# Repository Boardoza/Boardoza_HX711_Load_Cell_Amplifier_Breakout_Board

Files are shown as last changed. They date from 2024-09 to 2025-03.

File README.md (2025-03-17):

# Boardoza HX711 24-Bit ADC Module

The HX711 24-Bit Analog-to-Digital Converter (ADC) Module is designed for precision load cell measurements, making it ideal for electronic weighing scales and industrial control applications. It features a low-noise programmable gain amplifier and supports two selectable differential input channels. The module operates with low power consumption, making it suitable for battery-powered applications.

## [Click here to purchase!](https://ozdisan.com/maker-ve-iot-urunleri/boardoza/boardoza-modulleri/BOARDOZA-HX711/1206514)

|Front Side|Back Side|
|:---:|:---:|
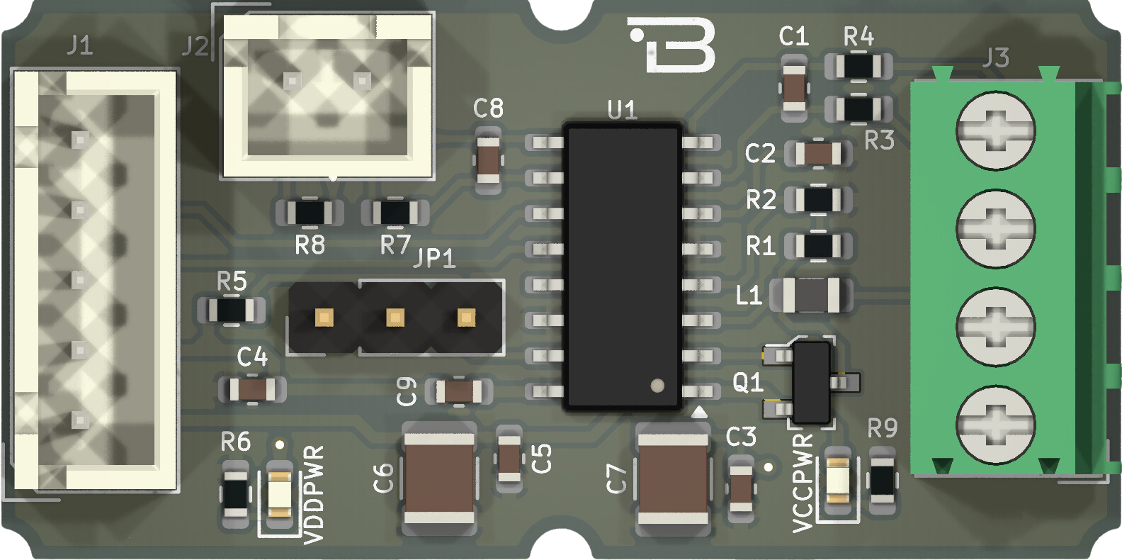
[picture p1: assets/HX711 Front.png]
HX711 Front
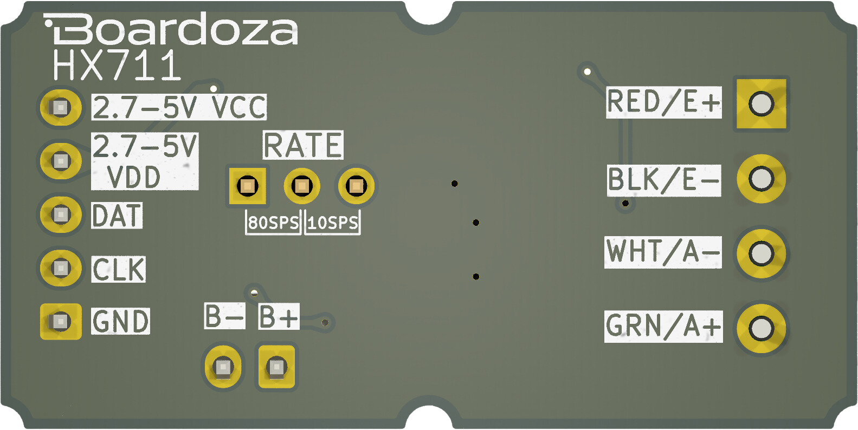
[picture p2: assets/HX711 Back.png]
HX711 Back
| | |

---

## Key Features

- 24-bit ADC designed for weigh scales and industrial applications.
- Two selectable differential input channels (To use channel B, R7(100R), R8(100R), and C8(100nF) must be populated).
- Low power consumption: <1.5mA in normal operation, <1µA in power-down mode.
- Integrated low-noise programmable gain amplifier.
- Selectable output data rates: 10SPS or 80SPS.
- Wide operating voltage range: 2.7V to 5.5V.

---

## Technical Specifications

**Input Voltage:** 2.7V - 5.5V  
**Functions:** 24-Bit ADC for load cells and weigh scales  
**Supply Current:** 1.5mA  
**Operating Temperature:** -40°C ~ +85°C  
**Board Dimensions:** 20mm x 40mm  

---

## Board Pinout

### J1 Connector

| Pin Number | Pin Name | Description |
| :---: | :---: | --- |
| 1 | VCC | 2.7V - 5.5V Power Input |
| 2 | VDD | 2.7V - 5.5V Power Input |
| 3 | DAT | Serial Data Output |
| 4 | CLK | Serial Clock Input |
| 5 | GND | Ground |

### J2 Connector

| Pin Number | Pin Name | Description |
| :---: | :---: | --- |
| 1 | B+ | Positive Signal (Second Channel) |
| 2 | B- | Negative Signal (Second Channel) |

### J3 Connector (Load Cell Interface)

| Pin Number | Pin Name | Description |
| :---: | :---: | --- |
| 1 | RED/E+ | + Excitation |
| 2 | BLK/E- | - Excitation |
| 3 | WHT/A- | - Signal |
| 4 | GRN/A+ | + Signal |

### JP1 Jumper Settings

| Pin Configuration | Data Rate |
| :---: | --- |
| 1-2 | 80 Samples per Second (SPS) |
| 2-3 | 10 Samples per Second (SPS) |

---

## Board Dimensions

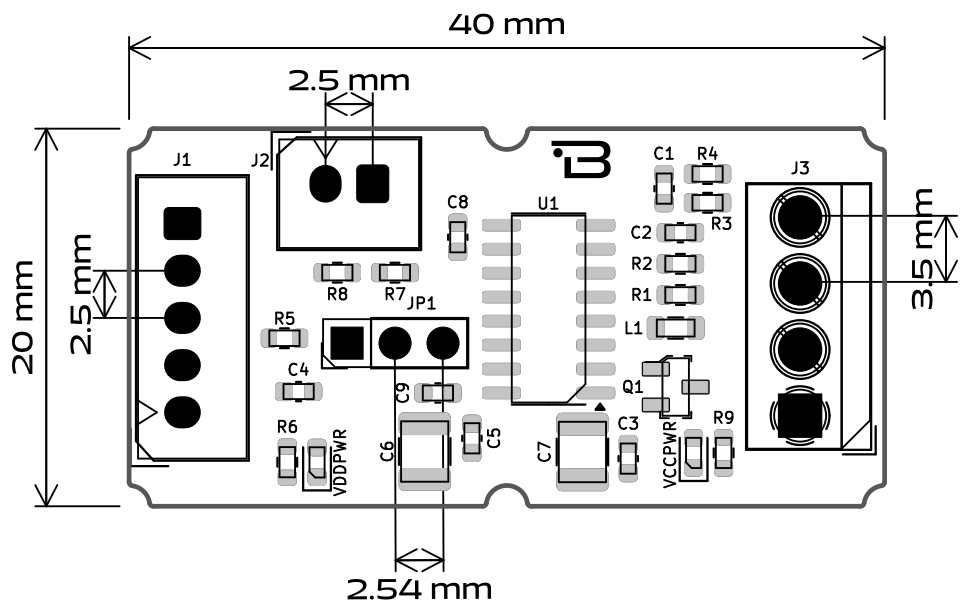
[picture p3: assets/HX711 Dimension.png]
HX711 Dimension


---

## Step Files

[Boardoza HX711.step](./assets/HX711%20Step.step)

---

## Datasheet

[Boardoza HX711 Datasheet.pdf](./assets/HX711%20Datasheet.pdf)

---

## Version History

- V1.0.0 - Initial Release

---

## Support

- If you have any questions or need support, please contact <support@boardoza.com>

---

## License

Shield: [][cc-by-sa]

This work is licensed under a [Creative Commons Attribution-ShareAlike 4.0 International License][cc-by-sa].

[][cc-by-sa]

[cc-by-sa]: http://creativecommons.org/licenses/by-sa/4.0/
[cc-by-sa-image]: https://licensebuttons.net/l/by-sa/4.0/88x31.png
[cc-by-sa-shield]: https://img.shields.io/badge/License-CC%20BY--SA%204.0-lightgrey.svg

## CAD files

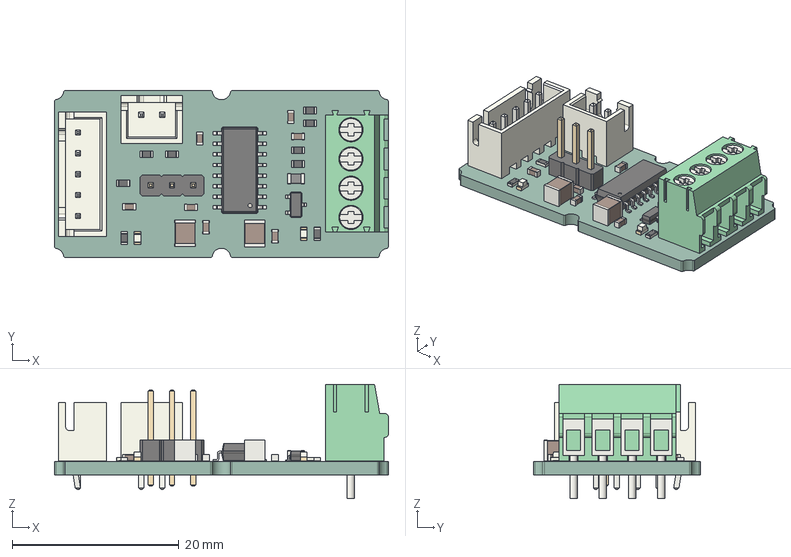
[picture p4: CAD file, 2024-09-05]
assets/HX711 Step.step
40.0 x 20.0 x 13.7 mm
R_0603_1608Metric x 9
LED_0603_1608Metric x 2
C_0603_1608Metric x 7
L_0805_2012Metric
TerminalBlock_Phoenix_PT_15_4_35_H_1x04_P350mm_Horizontal
C_1210_3225Metric x 2
JST_B5B_XH_A
SOP_16_44x104mm_P127mm
PinHeader_1x03_P254mm_Vertical
SOT_23
JST_B2B_XH_A
_autosave-B-HX711-BRK-01MBR-R01_PCB

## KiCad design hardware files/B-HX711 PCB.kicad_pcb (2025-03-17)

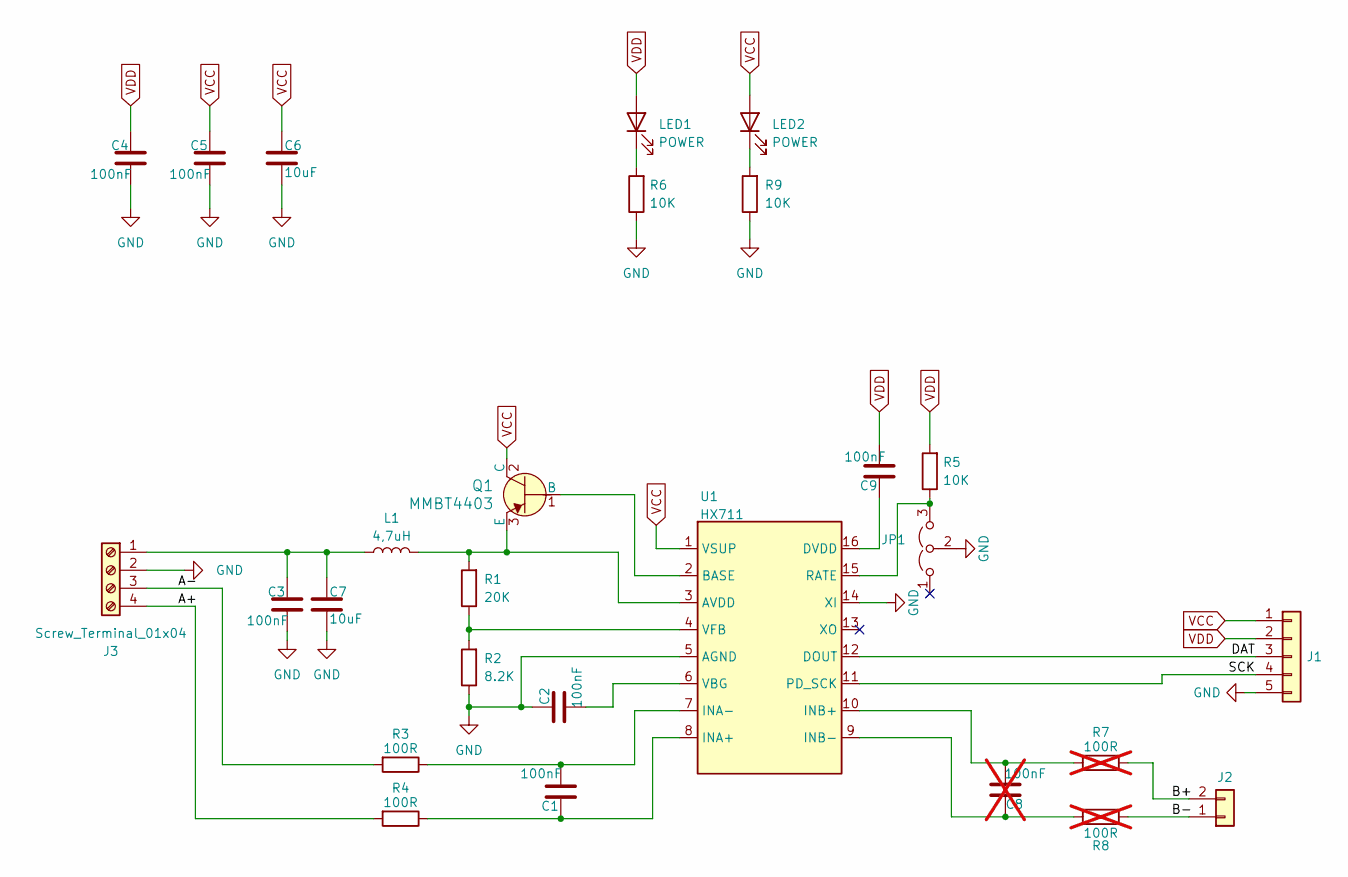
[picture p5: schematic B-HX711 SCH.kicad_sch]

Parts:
C1, C2, C3, C4, C5, C9: 100nF; C_0603_1608Metric; MPN CL10B104KB8NNNC
C6, C7: 10uF; C_1210_3225Metric; MPN CL10A106KQ8NNNC
C8: 100nF; C_0603_1608Metric; not fitted
J1: Conn_01x05; 2317-05S_1x05_P2.50mm_Vertical
J2: Conn_01x02; 2317-02S_1x02_P2.50mm_Vertical; MPN DG350-3.5-02P-14-00AH
J3: Screw_Terminal_01x04; TerminalBlock_MetzConnect_Type059_RT06304HBWC_1x04_P3.50mm_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; MPN DG350-3.5-02P-14-00AH
JP1: Jumper_3_Open; PinHeader_1x03_P2.54mm_Vertical; MPN L-KLS1-207-1-03-S
L1: 4,7uH; L_0805_2012Metric
LED1, LED2: POWER; LED_0603_1608Metric; MPN 19-213USRC/S259/TR8
Q1: MMBT4403; SOT-23-3; MPN MMBT4403_R1_00001
R1: 20K; R_0603_1608Metric; MPN 0603SAJ0203T5E
R2: 8.2K; R_0603_1608Metric; MPN 0603SAJ0822T5E
R3, R4: 100R; R_0603_1608Metric; MPN CQ03SAJ0101T5E
R5, R6, R9: 10K; R_0603_1608Metric; MPN 0603SAJ0103T5E
R7, R8: 100R; R_0603_1608Metric; not fitted
U1: HX711; SOP-16_3.9x9.9mm_P1.27mm; MPN HX711

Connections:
/A+: J3.4, R4.2
/A-: J3.3, R3.2
/B+: J2.2, R7.1
/B-: J2.1, R8.1
/DAT: J1.3, U1.12 (DOUT)
/SCK: J1.4, U1.11 (PD_SCK)
GND: C2.1, C3.1, C4.1, C5.1, C6.2, C7.2, J1.5, J3.2, JP1.2 (C), R2.1, R6.1, R9.1, U1.5 (AGND), U1.14 (XI)
unnamed: C3.2, C7.1, J3.1, L1.1
unnamed: JP1.3 (B), R5.1, U1.15 (RATE)
unnamed: LED1.1 (K), R6.2
unnamed: LED2.1 (K), R9.2
unnamed: Q1.1 (B), U1.2 (BASE)
unnamed: L1.2, Q1.3 (E), R1.2, U1.3 (AVDD)
unnamed: C9.1, U1.16 (DVDD)
unnamed: C1.1, R4.1, U1.8 (INA+)
unnamed: C1.2, R3.1, U1.7 (INA-)
unnamed: C8.2, R7.2, U1.10 (INB+)
unnamed: C8.1, R8.2, U1.9 (INB-)
unnamed: C2.2, U1.6 (VBG)
unnamed: R1.1, R2.2, U1.4 (VFB)
VCC: C5.2, C6.1, J1.1, LED2.2 (A), Q1.2 (C), U1.1 (VSUP)
VDD: C4.2, C9.2, J1.2, LED1.2 (A), R5.2

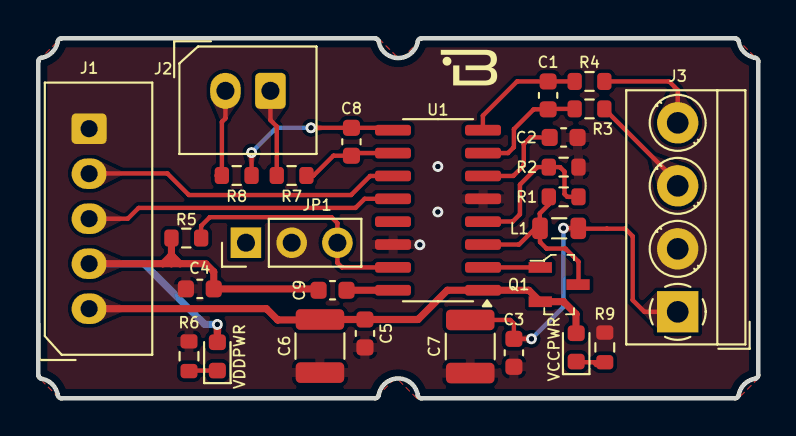
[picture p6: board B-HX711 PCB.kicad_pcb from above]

Board: 2 copper layers, 40.0 x 20.0 mm, 27 parts (0 on the bottom side), 22 nets.

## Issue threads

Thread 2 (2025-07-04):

SCHEMATIC?

lavara123, 2025-07-04:
SCHEMATIC mevcut mu veya vcc vdd ayrımı tam var mı yani

3v3 seviyesinde mcu:
3v3 = vdd
5v = vcc
GND = ortak

Tarzında kullanılabilir mi mcu ya zarar verir mi?

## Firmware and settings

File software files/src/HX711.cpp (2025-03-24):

#include "HX711.h"

int32_t offSetValue = 0;
/**
 * @brief Constructor for the HX711 class.
 * 
 * @param data Data pin connected to the HX711 module.
 * @param clock Clock pin connected to the HX711 module.
 */
HX711::HX711(byte data, byte clock) {
    dataPin = data;
    clockPin = clock;
}

/**
 * @brief Initializes the HX711 module.
 * 
 * This function initializes the HX711 module by beginning communication with Wire, setting data pin as INPUT, clock pin as OUTPUT,
 * powering down the module, delaying for 10 microseconds, and then powering up the module.
 */
void HX711::begin() {
    Wire.begin();
    pinMode(dataPin, INPUT);
    pinMode(clockPin, OUTPUT);
    powerDown();
    delayMicroseconds(10);
    powerUp();
}

/**
 * @brief Checks if the HX711 module is ready for data retrieval.
 * 
 * This function checks if the HX711 module is ready for data retrieval by reading the data pin and checking if it is LOW.
 * @return True if the module is ready, false otherwise.
 */
bool HX711::isReady() {
    return digitalRead(dataPin) == LOW;
}

/**
 * @brief Retrieves the raw value from the HX711 module.
 * 
 * This function retrieves the raw value from the HX711 module based on the specified channel gain.
 * It waits for the module to be ready, reads the data pins, and calculates the raw value.
 * 
 * @param chanGain The channel gain value to determine the raw value.
 * @return The raw value read from the HX711 module as a 32-bit integer.
 */
int32_t HX711::getRawValue(channelGain chanGain) {
    while(!isReady()) {
        // Wait for HX711 to ready
    }
    digitalWrite(clockPin, LOW);
    uint32_t value = 0;
    
    for (int i = 0; i < 24; i++) {
        digitalWrite(clockPin, HIGH);
        delayMicroseconds(10);
        value = (value << 1) | digitalRead(dataPin);
        digitalWrite(clockPin, LOW);
        delayMicroseconds(10);
    }

    for (int i = 0; i < chanGain - 24; i++) {
        digitalWrite(clockPin, HIGH);
        digitalWrite(clockPin, LOW);
    }
    if (value & 0x800000) {
        value |= 0xFF000000;
    }

    return (int32_t) value;
}

/**
 * @brief Performs tare operation on the HX711 module.
 * 
 * This function performs tare operation by taking multiple readings and calculating the average value as the offset value.
 * 
 * @param times The number of times to perform tare operation and calculate the offset value.
 */
void HX711::tare(byte times) {
    long sum = 0;

    for(byte i = 0; i < times; ++i) {
        sum += getRawValue();
        delay(100);
    }
    offSetValue = (sum / times);
}

/**
 * @brief Sets the offset value for the HX711 module.
 * 
 * This function sets the offset value for the HX711 module by subtracting the provided temporary ADC value from the stored offset value.
 * 
 * @param tempADCValue The temporary ADC value to be used in setting the offset.
 * @return The new offset value after setting it.
 */
int32_t HX711::setOffset( int32_t tempADCValue ) {
    return (tempADCValue - offSetValue);
}

/**
 * @brief Powers down the HX711 module.
 * 
 * This function powers down the HX711 module by setting the clock pin to HIGH.
 */
void HX711::powerDown() {
    digitalWrite(clockPin, HIGH);
}

/**
 * @brief Powers up the HX711 module.
 * 
 * This function powers up the HX711 module by setting the clock pin to LOW.
 */
void HX711::powerUp() {
    digitalWrite(clockPin, LOW);
}

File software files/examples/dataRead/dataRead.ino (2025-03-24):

#include <Arduino.h>
#include "HX711.h"

#define DOUT_PIN 2
#define CLK_PIN 3

HX711 scale(DOUT_PIN, CLK_PIN);
bool start_up=1;
void setup() {
  Serial.begin(115200);
  scale.begin();
  //scale.setGain(128); // You can set the gain value according to your load cell
  //scale.setCalibrationFactor(1000); // Set the calibration factor according to your setup
  
}

void loop() {
  if (start_up)
    {
    delay(100);
    scale.tare(10);
    start_up = 0; 
    }
  Serial.print(scale.setOffset( scale.getRawValue()) );
  Serial.println("  ");


  delay(100); // Delay for 100 milisecond before next reading
}

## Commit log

2024-09-05 Initial release of HX711 breakout board.
    [HX711 Step.step]
2025-03-17 Update README.md to enhance module description, design files and key features
    [B-HX711 PCB.kicad_pcb, B-HX711 SCH.kicad_sch]
